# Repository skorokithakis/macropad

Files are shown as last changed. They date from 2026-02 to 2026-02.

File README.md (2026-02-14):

# Stavropad

A 4x4 macro pad running ZMK firmware on a Nice!Nano v2.

## Features

- 15 normal layers with 15 usable keys each
- Layer switching via dedicated layer-switching key
- All hotkey layers send RCtrl+Shift+Cmd + a character (for use as global hotkeys)
- Idle deep sleep enabled; wakes on any key press after inactivity
- 15 Bluetooth profiles via dedicated Bluetooth control screen

## Layer access

Hold the layer-switching key (bottom-right, key 15) to activate the layer switcher. While holding it:

**Normal layers (tap):**
- Tap keys 0-11 to switch to normal layers 0-11.
- Tap keys 12-14 to switch to normal layers 12-14.

**Special layers (hold for 1 second, ordered by increasing danger):**
- Key 0: Type battery voltage (for example: "Battery: 3.98V").
- Key 1: Open Bluetooth control.
- Key 2: Enter bootloader mode.

## Layers

See [KEYMAPS.md](KEYMAPS.md) for visual layer references.

```
Key positions:
 0   1   2   3
 4   5   6   7
 8   9  10  11
12  13  14  15
```

**Normal layers**

- **Layer 0**: Hotkeys (numbers and symbols)
- **Layer 1**: Hotkeys (letters A-P)
- **Layer 2**: Hotkeys (letters Q-Z and punctuation)
- **Layer 3**: Hotkeys (function keys and modifiers)
- **Layer 4**: Text macros
- **Layer 5**: Media controls
- **Layer 6**: Mouse control
- **Layer 7**: Gaming
- **Layer 8**: Numpad
- **Layer 9**: Cluster
- **Layer 10**: OnShape Sketch Tools
- **Layers 11-14**: Placeholder layers

**Special layers**

- **Bluetooth control**: Select Bluetooth profiles 0-14 and clear bonds.
- **Battery voltage**: Types a voltage readout.
- **Bootloader**: Enters bootloader mode.

**OnShape sub layers (accessed from Layer 10)**

- **Layer 18**: OnShape Constraints (hold key 10). Shortcuts: D, H, V, I, T, E, B, Shift + L, Shift + O, Shift + M, Shift + Q, Shift + J, Shift + K, Shift + U, Shift + G.
- **Layer 19**: OnShape Features (hold Escape). Shortcuts: Shift + E (Extrude), Shift + W (Revolve), Shift + F (Fillet). Remaining keys are empty.
- **Layer 20**: OnShape Numbers (hold key 11). Numpad layout (7-8-9, 4-5-6, 1-2-3, 0) with *, mm macro, +, decimal point, and backspace.
## Customize

Edit `config/stavropad.keymap`.

## Building

Run the build script:

```bash
./build.sh        # PCB version (default)
./build.sh -v 1   # Hand-wired version
./build.sh -v 2   # PCB version
```

This uses Docker to build the firmware. Output is `build/zephyr/zmk.uf2`.
The custom shield and keymap live under `config/boards/shields/stavropad`.

Pin mappings for each version are in `pins_v1.overlay` and `pins_v2.overlay`.

## Flashing

1. Put the board in bootloader mode (hold the layer-switching key + hold key 2 for 1 second).
2. Copy `build/zephyr/zmk.uf2` to the USB mass storage device that appears.

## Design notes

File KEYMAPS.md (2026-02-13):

# Keymaps

Visual reference for all keymap layers.

## Layer 0: Numbers and Symbols

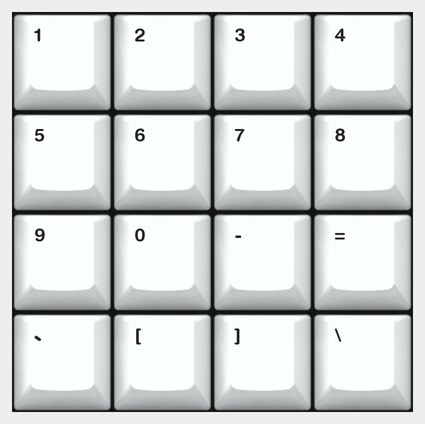
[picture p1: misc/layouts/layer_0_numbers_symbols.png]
Layer 0: Numbers and Symbols


## Layer 1: Letters A-P

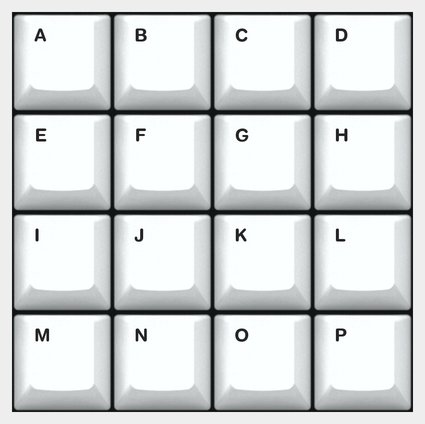
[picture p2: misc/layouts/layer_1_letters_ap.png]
Layer 1: Letters A-P


## Layer 2: Letters Q-Z

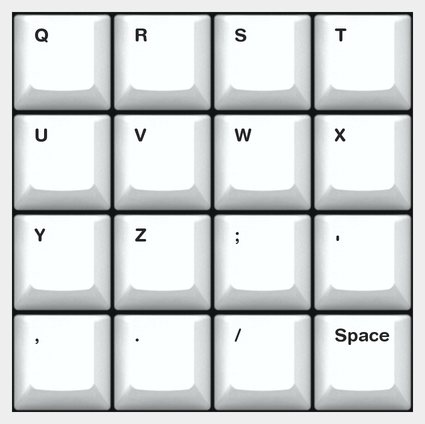
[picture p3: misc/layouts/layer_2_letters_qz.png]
Layer 2: Letters Q-Z


## Layer 3: Function Keys

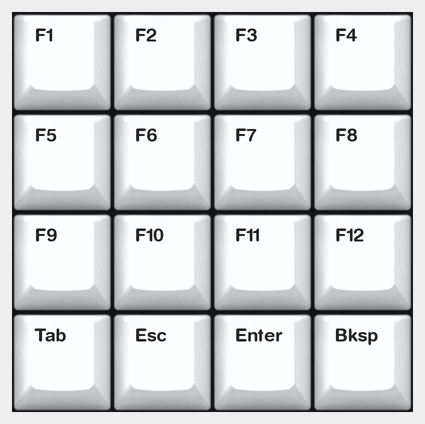
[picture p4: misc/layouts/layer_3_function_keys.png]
Layer 3: Function Keys


## Layer 4: Phrases

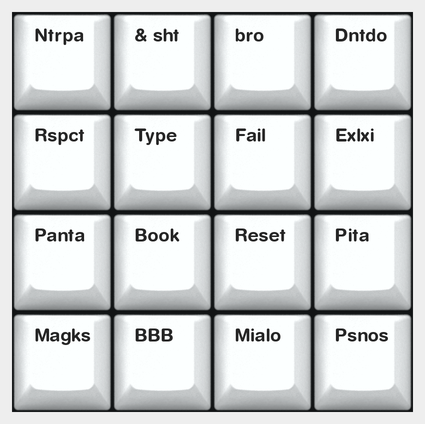
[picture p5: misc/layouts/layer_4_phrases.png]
Layer 4: Phrases


## Layer 5: Media Controls

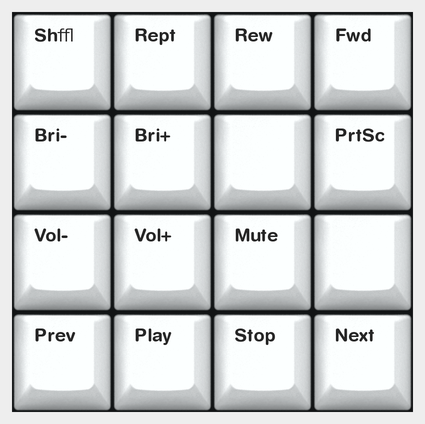
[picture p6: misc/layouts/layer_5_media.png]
Layer 5: Media Controls


## Layer 6: Mouse

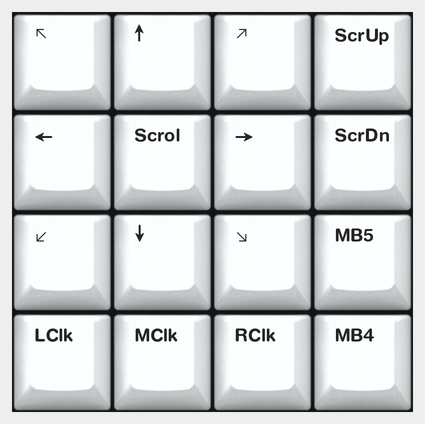
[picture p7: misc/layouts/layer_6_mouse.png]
Layer 6: Mouse


## Layer 7: Gaming

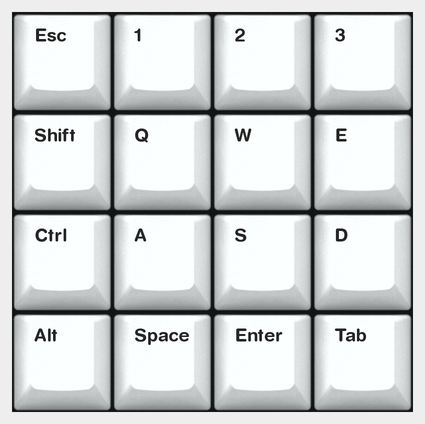
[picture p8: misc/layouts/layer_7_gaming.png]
Layer 7: Gaming


## Layer 8: Numpad

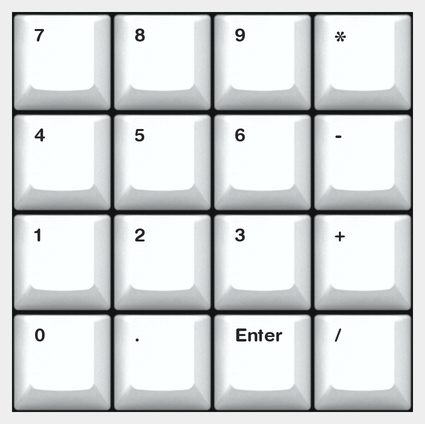
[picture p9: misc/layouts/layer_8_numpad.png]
Layer 8: Numpad


## Layer 9: QWERTY

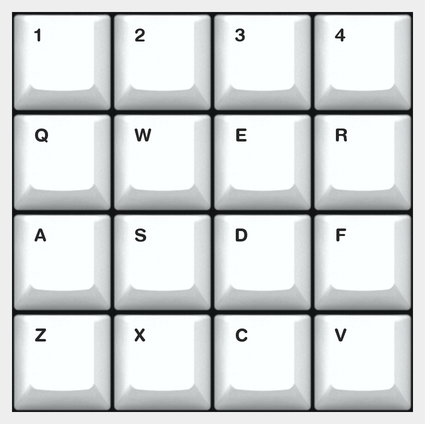
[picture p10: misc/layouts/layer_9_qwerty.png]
Layer 9: QWERTY


## Layer 10: OnShape Sketch Tools

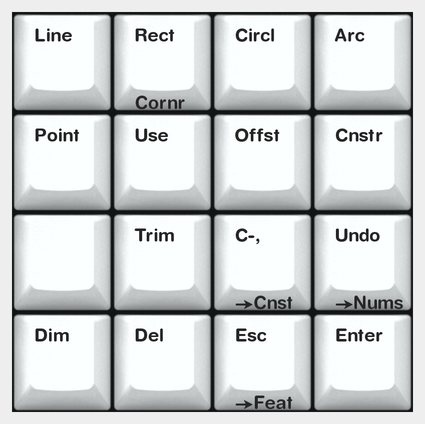
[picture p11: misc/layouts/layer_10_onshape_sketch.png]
Layer 10: OnShape Sketch Tools


## Layer 18: OnShape Constraints

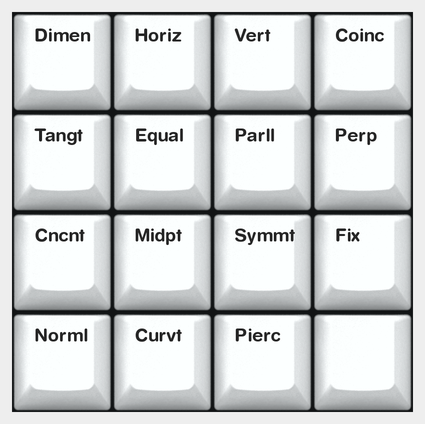
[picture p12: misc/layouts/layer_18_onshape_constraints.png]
Layer 18: OnShape Constraints


## Layer 19: OnShape Features

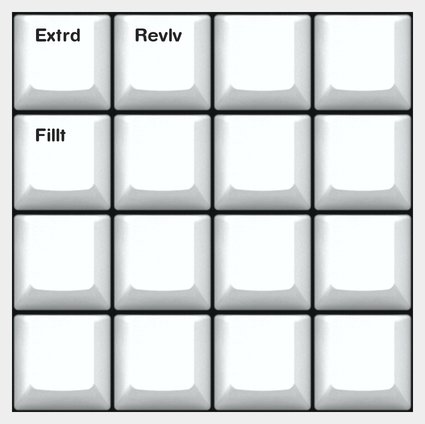
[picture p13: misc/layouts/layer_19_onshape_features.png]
Layer 19: OnShape Features


## Layer 20: OnShape Numbers

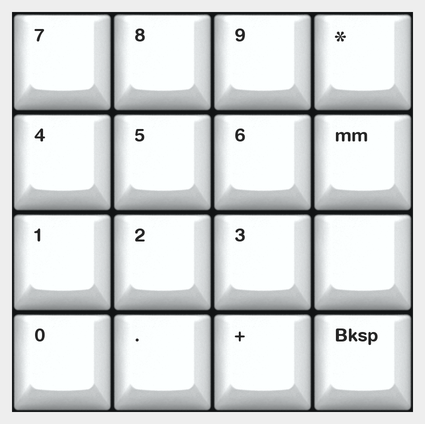
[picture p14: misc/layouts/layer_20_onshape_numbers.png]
Layer 20: OnShape Numbers


## Layer 11: Placeholder

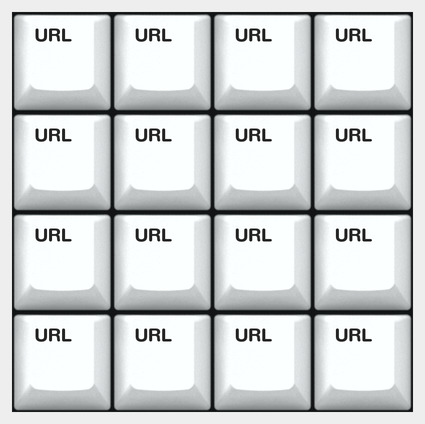
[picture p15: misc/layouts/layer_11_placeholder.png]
Layer 11: Placeholder


## Layer 12: Placeholder

Layer 12: Placeholder

## Layer 13: Placeholder

Layer 13: Placeholder

## Layer 14: Placeholder

Layer 14: Placeholder

## Layer 15: Bluetooth

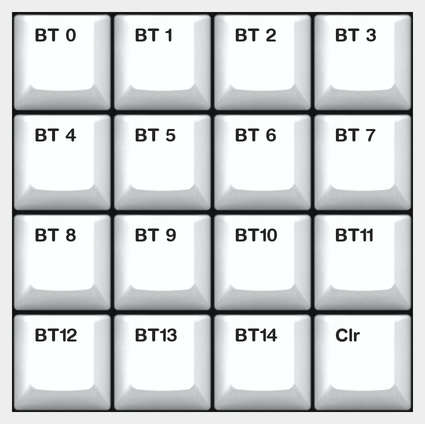
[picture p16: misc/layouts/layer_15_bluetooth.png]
Layer 15: Bluetooth


## Layer 16: Layer Select

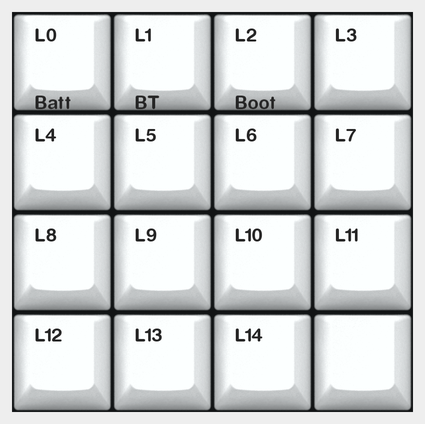
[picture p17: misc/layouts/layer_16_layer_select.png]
Layer 16: Layer Select


## Layer 17: Scroll

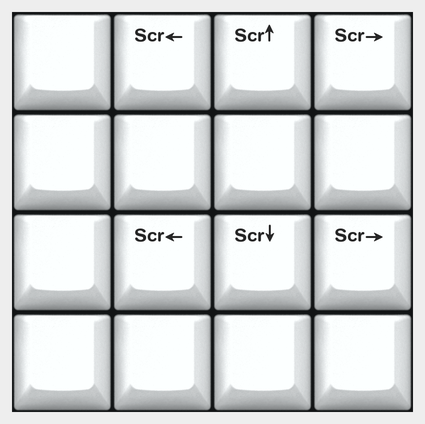
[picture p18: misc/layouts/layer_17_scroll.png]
Layer 17: Scroll


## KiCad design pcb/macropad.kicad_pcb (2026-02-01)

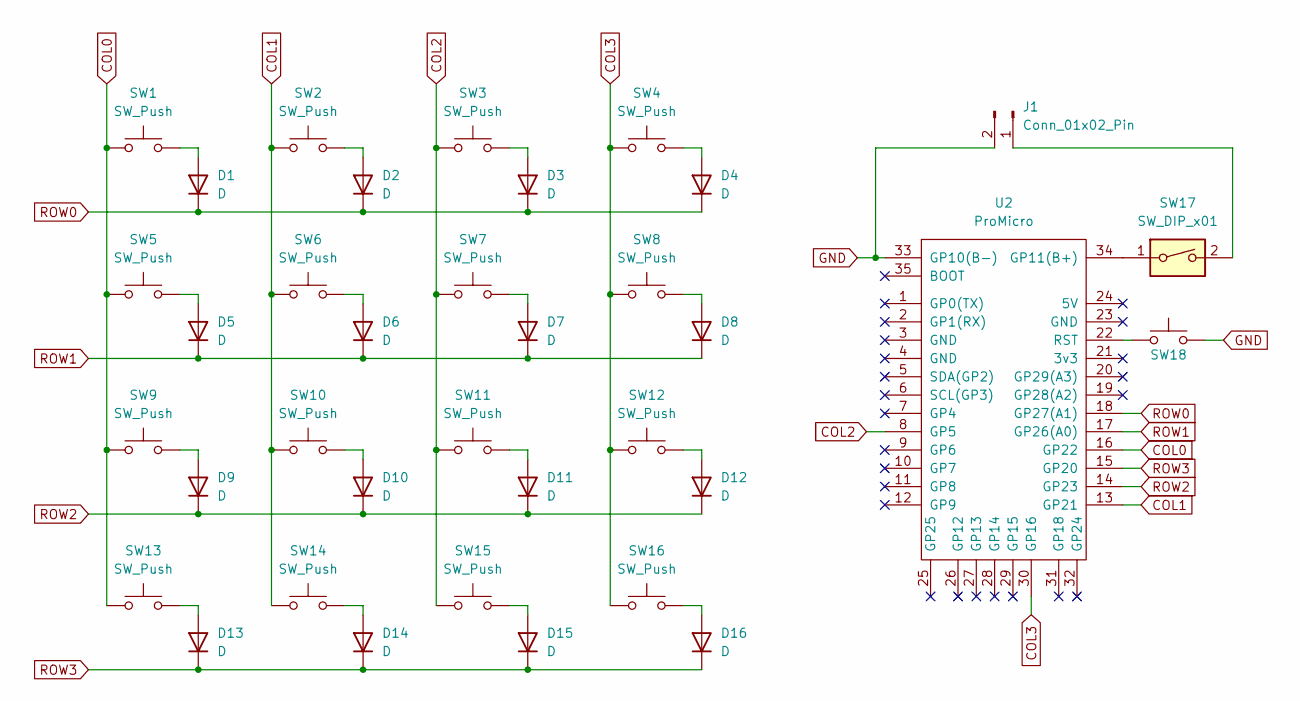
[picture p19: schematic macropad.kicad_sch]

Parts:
D1, D2, D3, D4, D5, D6, D7, D8, D9, D10, D11, D12, D13, D14, D15, D16: D; D_SOD-323; LCSC C2128
J1: Conn_01x02_Pin; PinHeader_1x02_P2.54mm_Vertical
SW1, SW2, SW3, SW4, SW5, SW6, SW7, SW8, SW9, SW10, SW11, SW12, SW13, SW14, SW15, SW16: SW_Push; SW_MX_Kailh_Choc_V1V2_HotSwap_Hybrid
SW17: SW_DIP_x01; SW_SPDT_Shouhan_MSK12C02
SW18: SW_Push; SW_SPST_TS-1088-xR020; LCSC C720477
U2: ProMicro; TheOneProMacro

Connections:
COL0: SW1.1, SW5.1, SW9.1, SW13.1, U2.16 (GP22)
COL1: SW2.1, SW6.1, SW10.1, SW14.1, U2.13 (GP21)
COL2: SW3.1, SW7.1, SW11.1, SW15.1, U2.8 (GP5)
COL3: SW4.1, SW8.1, SW12.1, SW16.1, U2.30 (GP16)
GND: J1.2, SW18.2, U2.33 (GP10(B-))
unnamed: D1.2 (A), SW1.2
unnamed: D2.2 (A), SW2.2
unnamed: D3.2 (A), SW3.2
unnamed: D4.2 (A), SW4.2
unnamed: D5.2 (A), SW5.2
unnamed: D6.2 (A), SW6.2
unnamed: D7.2 (A), SW7.2
unnamed: D8.2 (A), SW8.2
unnamed: D9.2 (A), SW9.2
unnamed: D10.2 (A), SW10.2
unnamed: D11.2 (A), SW11.2
unnamed: D12.2 (A), SW12.2
unnamed: D13.2 (A), SW13.2
unnamed: D14.2 (A), SW14.2
unnamed: D15.2 (A), SW15.2
unnamed: D16.2 (A), SW16.2
unnamed: J1.1, SW17.2
unnamed: SW17.1, U2.34 (GP11(B+))
unnamed: SW18.1, U2.22 (RST)
ROW0: D1.1 (K), D2.1 (K), D3.1 (K), D4.1 (K), U2.18 (GP27(A1))
ROW1: D5.1 (K), D6.1 (K), D7.1 (K), D8.1 (K), U2.17 (GP26(A0))
ROW2: D9.1 (K), D10.1 (K), D11.1 (K), D12.1 (K), U2.14 (GP23)
ROW3: D13.1 (K), D14.1 (K), D15.1 (K), D16.1 (K), U2.15 (GP20)

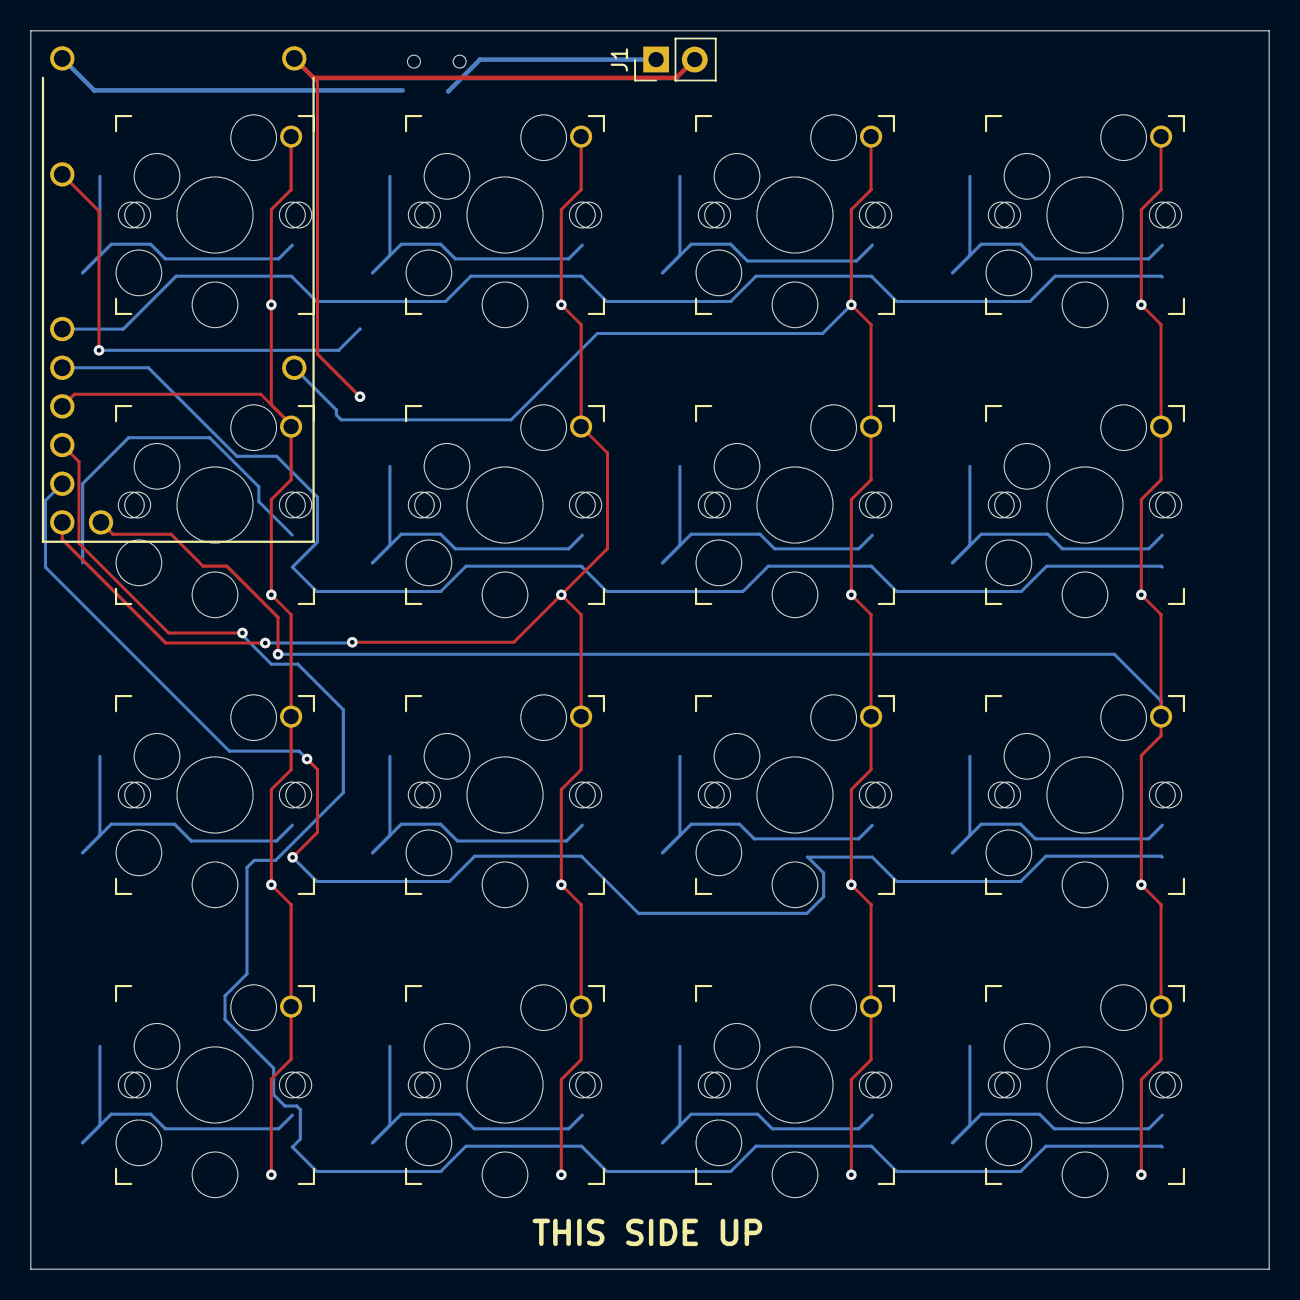
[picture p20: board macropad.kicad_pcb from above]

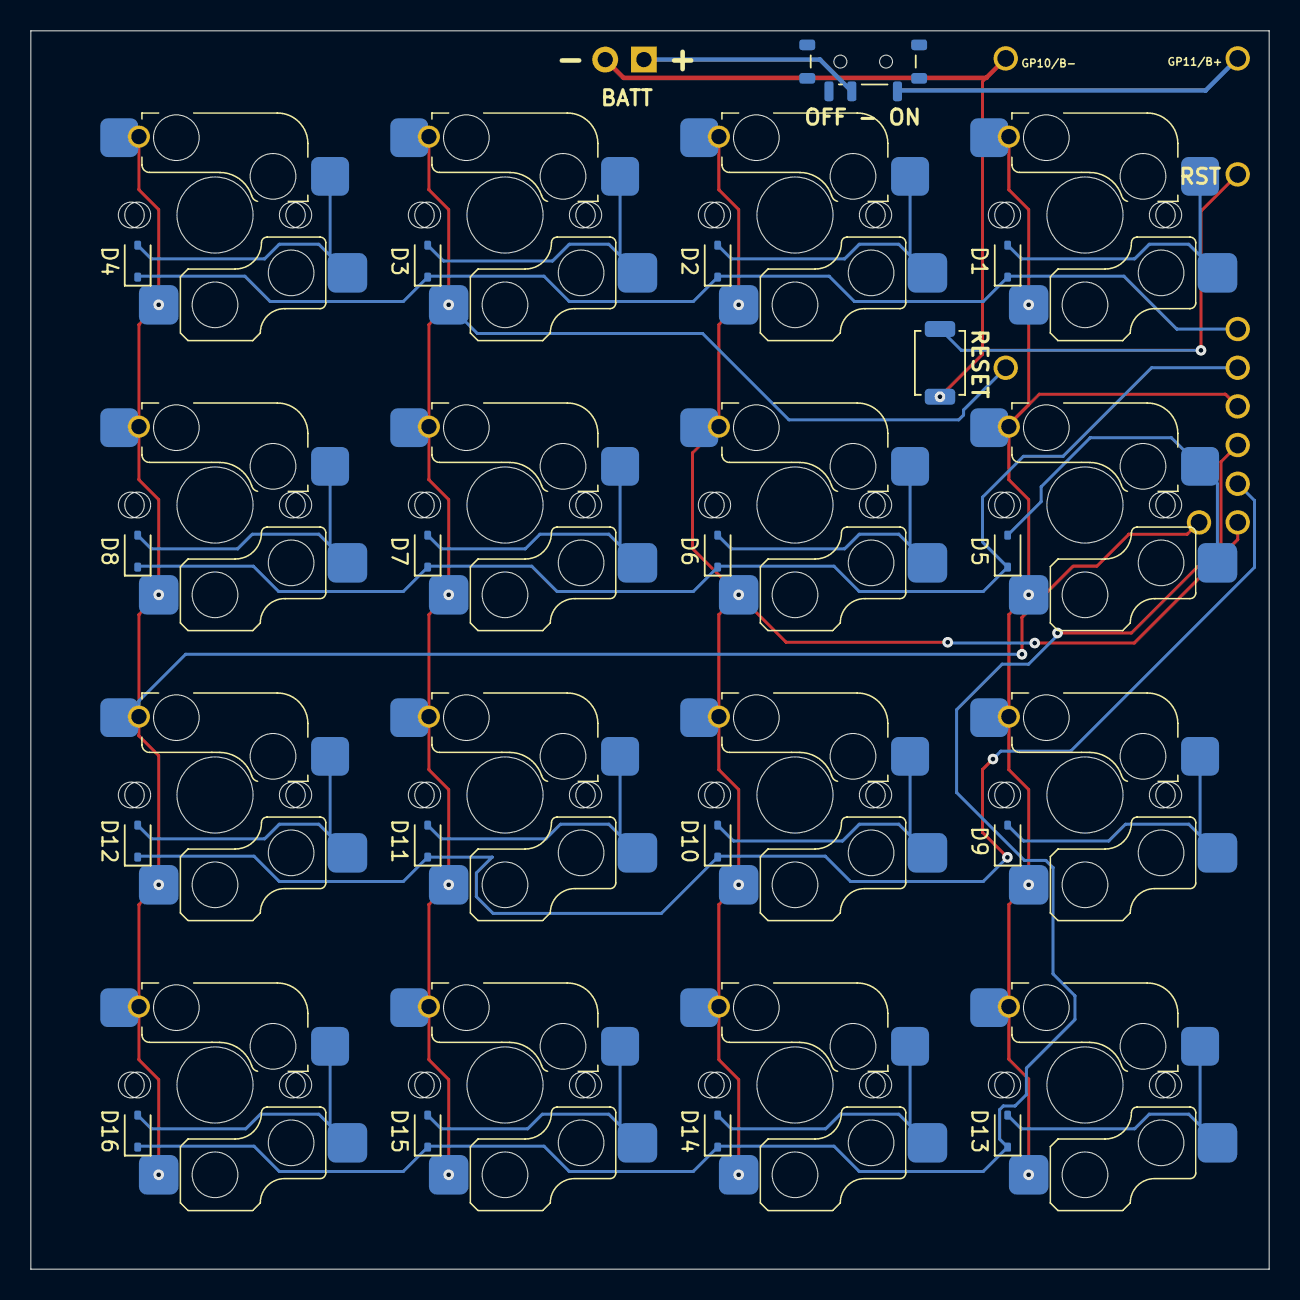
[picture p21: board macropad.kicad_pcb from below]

Board: 2 copper layers, 81.3 x 81.3 mm, 36 parts (18 on the bottom side), 28 nets.

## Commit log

2025-12-31 Use right control key instead of left control for shortcuts
    Switches all keyboard shortcuts from LC (left control) to RC (right control)
    to avoid conflicts with caps lock when users have swapped caps and control keys.
2025-12-31 Add battery voltage display key combination (#2)
    * Add battery voltage display key combination
    - Add battery_voltage_macro that types "Battery: 3.98V"
    - Configure combo for middle two layer buttons (1 and 2) to trigger the macro
    - Update README to document the new feature
    - Note: Displays static voltage value; real-time voltage would require custom firmware
    * Implement real-time battery voltage display with custom ZMK behavior
    Replace static battery voltage macro with a custom ZMK behavior that reads
    actual battery voltage on-demand. This implementation:
    - Adds batt_type custom behavior module that reads battery sensor
    - Reads voltage via standard ZMK battery API (/chosen zmk,battery)
    -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
2026-01-01 Add battery typing delays
2026-01-04 Add PCB (#5)
    [macropad.kicad_pcb, macropad.kicad_sch]
2026-01-04 Add media control layer (layer 5, buttons 0+2)
    Layer includes brightness, volume, playback controls, shuffle/repeat, and search.
2026-01-21 Fix +/- silkscreen
    [macropad.kicad_pcb]
2026-01-21 Change pin assignments to the PCB ones
2026-01-21 Add selectable v1/v2 pin overlays and update build/docs
2026-01-26 Revise layer switching and remap layers/special functions
2026-02-01 Change silkscreen text from ON/OFF to OFF - ON
    [macropad.kicad_pcb]
2026-02-14 Move layer-switching key from key 12 (bottom-left) to key 15 (bottom-right)
    Shift bottom-row bindings (keys 13-15 → 12-14) on all 21 layers.
    Resolve hold-down conflicts on the new layer-switching position:
    - Layer 6 (Mouse): rotate all columns left so right-click isn't on key 15
    - Layer 7 (Gaming): swap Space and Enter so Space isn't on key 15
    - Layer 10 (OnShape): move hold-for-constraints from key 15 to key 10
    - Layer 20 (OnShape Numbers): move Backspace from key 15 to key 11
    Rename os_enter_constraints to os_hold_constraints.
    Update layout JSONs, README, and AGENTS.md.
